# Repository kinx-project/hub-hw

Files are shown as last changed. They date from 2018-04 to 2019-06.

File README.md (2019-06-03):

This repository contains the hardware design files for the kinX USB hub, a
bus-powered 4-port (2 internal, 2 external) USB hub for use within the Kinesis
Advantage keyboard in combination with the kinX keyboard controller.

The kinX USB hub is based on the Cypress HX2VL series USB controller,
specifically the [Cypress
CY7C65632-48AXCT](http://www.cypress.com/part/cy7c65632-48axct).

The design has been created with the following resources:

* [CY7C65632-48AXCT datasheet](http://www.cypress.com/file/114101/download)
* [HX2VL: Guidelines on System Design](http://www.cypress.com/file/122726/download)
* [CY4607M (CY7C65632-48AXCT devboard) schematic and BOM](http://www.cypress.com/documentation/other-resources/reduced-bom-schematic-cy7c65642-family-hx2vl-usb-20-hub-controller)
* [Example schematic for the QFN28 version](http://www.cypress.com/file/117521/download)

You can order this PCB at [OSH Park](https://oshpark.com/shared_projects/0aJAMwpd).

You can order the components at [Digi-Key](https://www.digikey.ch/short/pm8417).

## See also

https://github.com/kinx-project/mk66f-blaster for writing the EEPROM.

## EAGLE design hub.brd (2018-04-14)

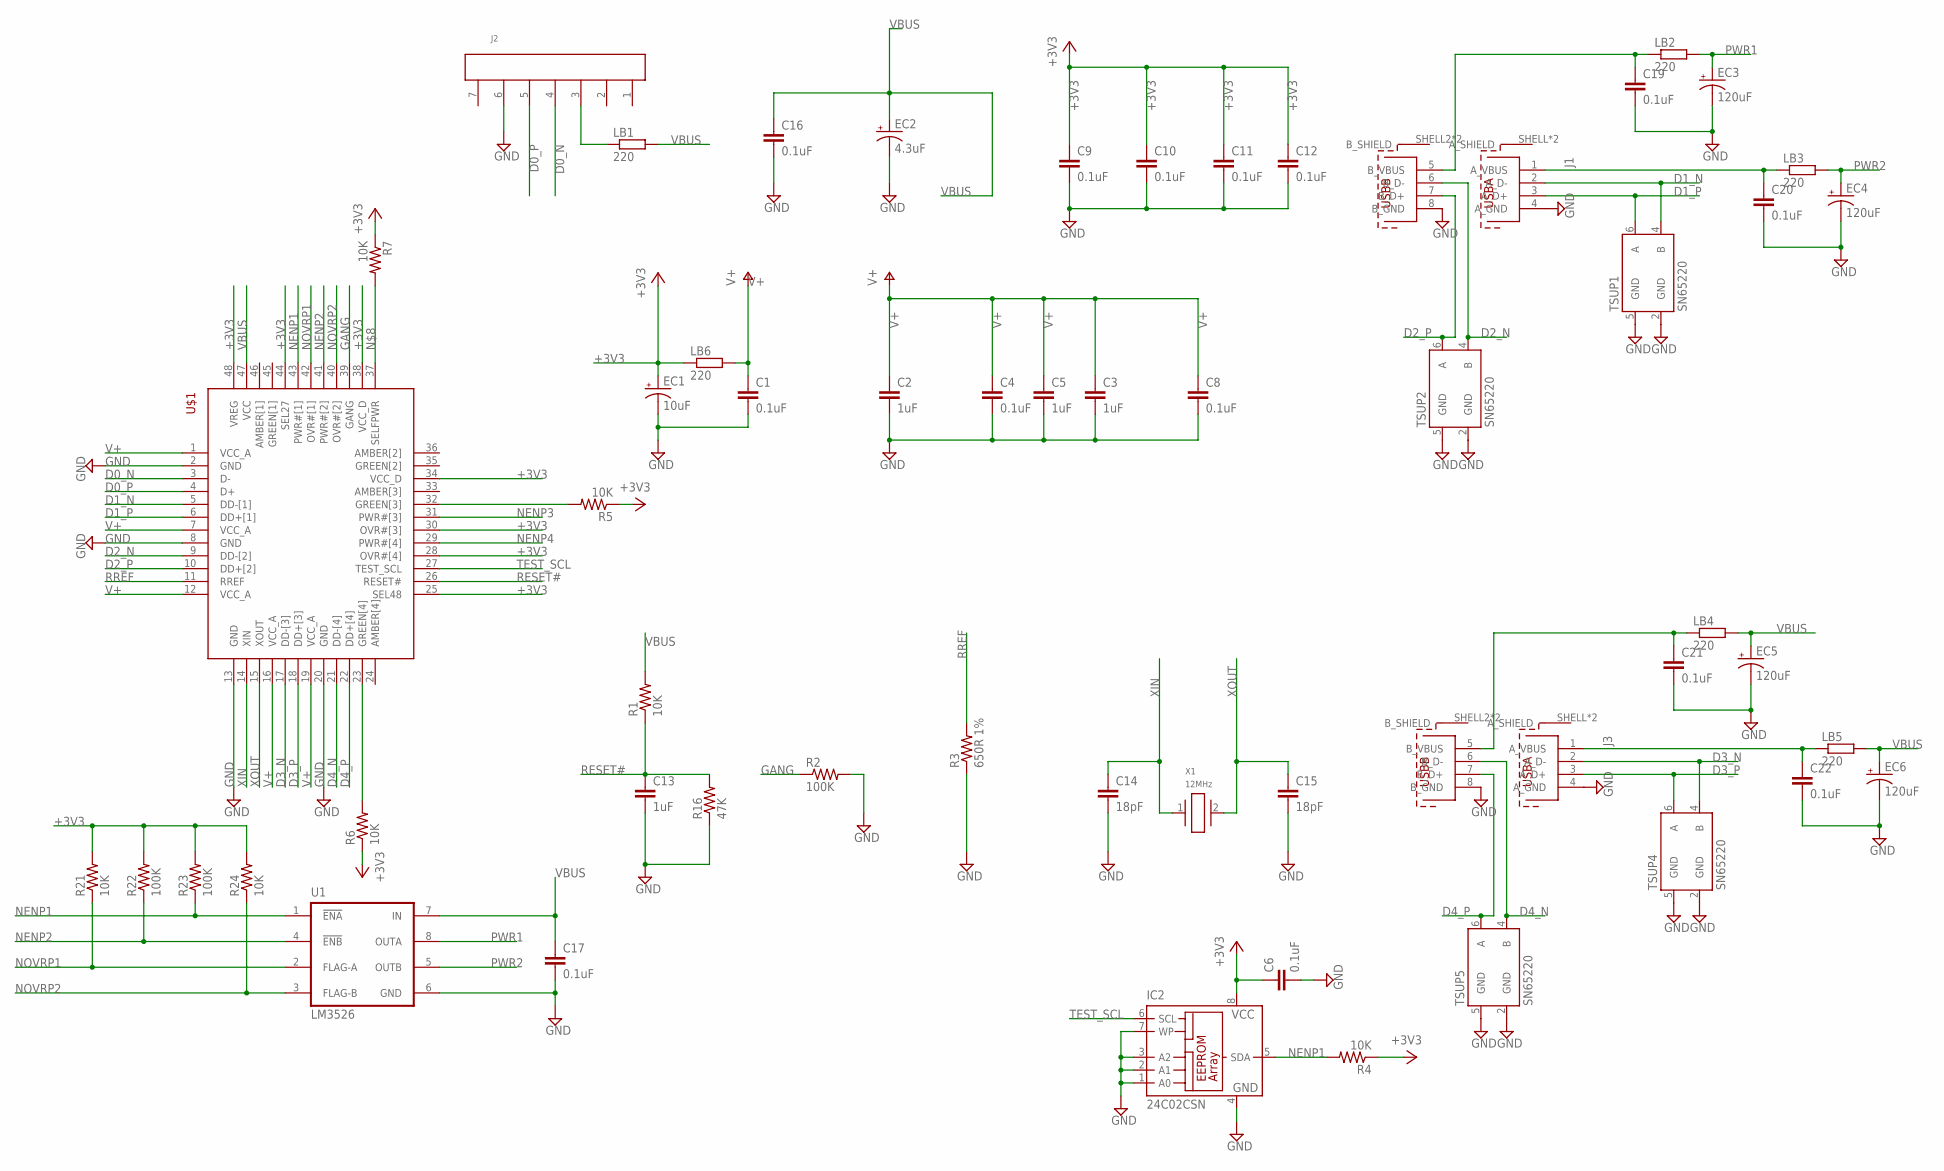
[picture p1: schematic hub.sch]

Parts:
C1, C4, C6, C8, C9, C10, C11, C12, C16, C17, C19, C20, C21, C22: 0.1uF; C0805; MPN GRM21BR71H104KA01L; DIGIKEY 732-8026-1-ND
C2, C3, C5, C13: 1uF; C0805; MPN C0805C105K4RACTU; DIGIKEY 399-1284-1-ND
C14, C15: 18pF; C0805; MPN CL21C180JBANNNC; DIGIKEY 1276-1107-1-ND
EC1: 10uF; CPOL-RADIAL-2.5MM-6.5MM; MPN UST1H100MDD1TE; DIGIKEY 493-16013-1-ND
EC2: 4.3uF; UD-5X5,8_NICHICON; MPN UUP1C4R7MCL1GS; DIGIKEY 338-3973-1-ND
EC3, EC4, EC5, EC6: 120uF; CPOL-RADIAL-2.5MM-6.5MM; MPN ELXY250ELL121MF15D; DIGIKEY 565-1791-ND
IC2: 24C02CSN; SO-08; DIGIKEY 24C02C/SN-ND
J1, J3: 61400826021; MPN 61400826021; DIGIKEY 732-2107-ND
J2: 62000711622; MPN 440054-7; DIGIKEY A100039-ND
LB1, LB2, LB3, LB4, LB5, LB6: 220; R0805; MPN BLM21PG221SN1D; DIGIKEY 490-1054-1-ND
R1, R4, R5, R6, R7, R21, R24: 10K; M0805; MPN RC0805FR-0710KL; DIGIKEY 311-10.0KCRCT-ND
R2, R22, R23: 100K; M0805; MPN RC0805FR-07100KL; DIGIKEY 311-100KCRCT-ND
R3: 650R 1%; M0805; MPN RC0805FR-07649RL; DIGIKEY 311-649CRCT-ND
R16: 47K; M0805; MPN RC0805FR-0747KL; DIGIKEY 311-47.0KCRCT-ND
TSUP1, TSUP2, TSUP4, TSUP5: SN65220; SOT23-6; MPN SN65220DBVR; DIGIKEY 296-9694-1-ND
U1: LM3526; SO08; MPN LM3526MX-L/NOPB; DIGIKEY LM3526MX-L/NOPBCT-ND
U$1: CY7C65632; TQFP48_7X7; MPN CY7C65632-48AXCT; DIGIKEY 428-3155-1-ND
X1: 12MHz; XTAL_ABLS2-24.000MHZ-D4YF-T; MPN ABLS-12.000MHZ-B2-T; DIGIKEY 535-9067-1-ND

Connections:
+3V3: C6.1, C9.1, C10.1, C11.1, C12.1, EC1.1 (+), IC2.8 (VCC), LB6.1, R4.1, R5.1, R6.1, R7.1, R21.2, R22.2, R23.2, R24.2, U$1.25 (SEL48), U$1.28 (OVR#[4]), U$1.30 (OVR#[3]), U$1.34 (VCC_D), U$1.38 (VCC_D), U$1.44 (SEL27), U$1.48 (VREG)
D0_N: J2.4, U$1.3 (D-)
D0_P: J2.5, U$1.4 (D+)
D1_N: J1.2 (A_D-), TSUP1.4 (B), U$1.5 (DD-[1])
D1_P: J1.3 (A_D+), TSUP1.6 (A), U$1.6 (DD+[1])
D2_N: J1.6 (B_D-), TSUP2.4 (B), U$1.9 (DD-[2])
D2_P: J1.7 (B_D+), TSUP2.6 (A), U$1.10 (DD+[2])
D3_N: J3.2 (A_D-), TSUP4.4 (B), U$1.17 (DD-[3])
D3_P: J3.3 (A_D+), TSUP4.6 (A), U$1.18 (DD+[3])
D4_N: J3.6 (B_D-), TSUP5.4 (B), U$1.21 (DD-[4])
D4_P: J3.7 (B_D+), TSUP5.6 (A), U$1.22 (DD+[4])
GANG: R2.1, U$1.39 (GANG)
GND: C1.2, C2.2, C3.2, C4.2, C5.2, C6.2, C8.2, C9.2, C10.2, C11.2, C12.2, C13.2, C14.2, C15.2, C16.2, C17.2, C19.2, C20.2, C21.2, C22.2, EC1.2 (-), EC2.-, EC3.2 (-), EC4.2 (-), EC5.2 (-), EC6.2 (-), IC2.1 (A0), IC2.2 (A1), IC2.3 (A2), IC2.4 (GND), IC2.7 (WP), J1.4 (A_GND), J1.8 (B_GND), J2.6, J3.4 (A_GND), J3.8 (B_GND), R2.2, R3.1, R16.1, TSUP1.2 (GND), TSUP1.5 (GND), TSUP2.2 (GND), TSUP2.5 (GND), TSUP4.2 (GND), TSUP4.5 (GND), TSUP5.2 (GND), TSUP5.5 (GND), U1.6 (GND), U$1.2 (GND), U$1.8 (GND), U$1.13 (GND), U$1.20 (GND)
unnamed: C19.1, J1.5 (B_VBUS), LB2.1
unnamed: C21.1, J3.5 (B_VBUS), LB4.1
unnamed: C22.1, J3.1 (A_VBUS), LB5.1
unnamed: C20.1, J1.1 (A_VBUS), LB3.1
unnamed: J2.3, LB1.1
unnamed: R6.2, U$1.23 (GREEN[4])
unnamed: R5.2, U$1.32 (GREEN[3])
unnamed: R7.2, U$1.37 (SELFPWR)
NENP1: IC2.5 (SDA), R4.2, R23.1, U1.1 (!ENA!), U$1.43 (PWR#[1])
NENP2: R22.1, U1.4 (!ENB!), U$1.41 (PWR#[2])
NENP3: U$1.31 (PWR#[3])
NENP4: U$1.29 (PWR#[4])
NOVRP1: R21.1, U1.2 (FLAG-A), U$1.42 (OVR#[1])
NOVRP2: R24.1, U1.3 (FLAG-B), U$1.40 (OVR#[2])
PWR1: EC3.1 (+), LB2.2, U1.8 (OUTA)
PWR2: EC4.1 (+), LB3.2, U1.5 (OUTB)
RESET#: C13.1, R1.1, R16.2, U$1.26 (RESET#)
RREF: R3.2, U$1.11 (RREF)
TEST_SCL: IC2.6 (SCL), U$1.27 (TEST_SCL)
V+: C1.1, C2.1, C3.1, C4.1, C5.1, C8.1, LB6.2, U$1.1 (VCC_A), U$1.7 (VCC_A), U$1.12 (VCC_A), U$1.16 (VCC_A), U$1.19 (VCC_A)
VBUS: C16.1, C17.1, EC2.+, EC5.1 (+), EC6.1 (+), LB1.2, LB4.2, LB5.2, R1.2, U1.7 (IN), U$1.47 (VCC)
XIN: C14.1, U$1.14 (XIN), X1.1
XOUT: C15.1, U$1.15 (XOUT), X1.2

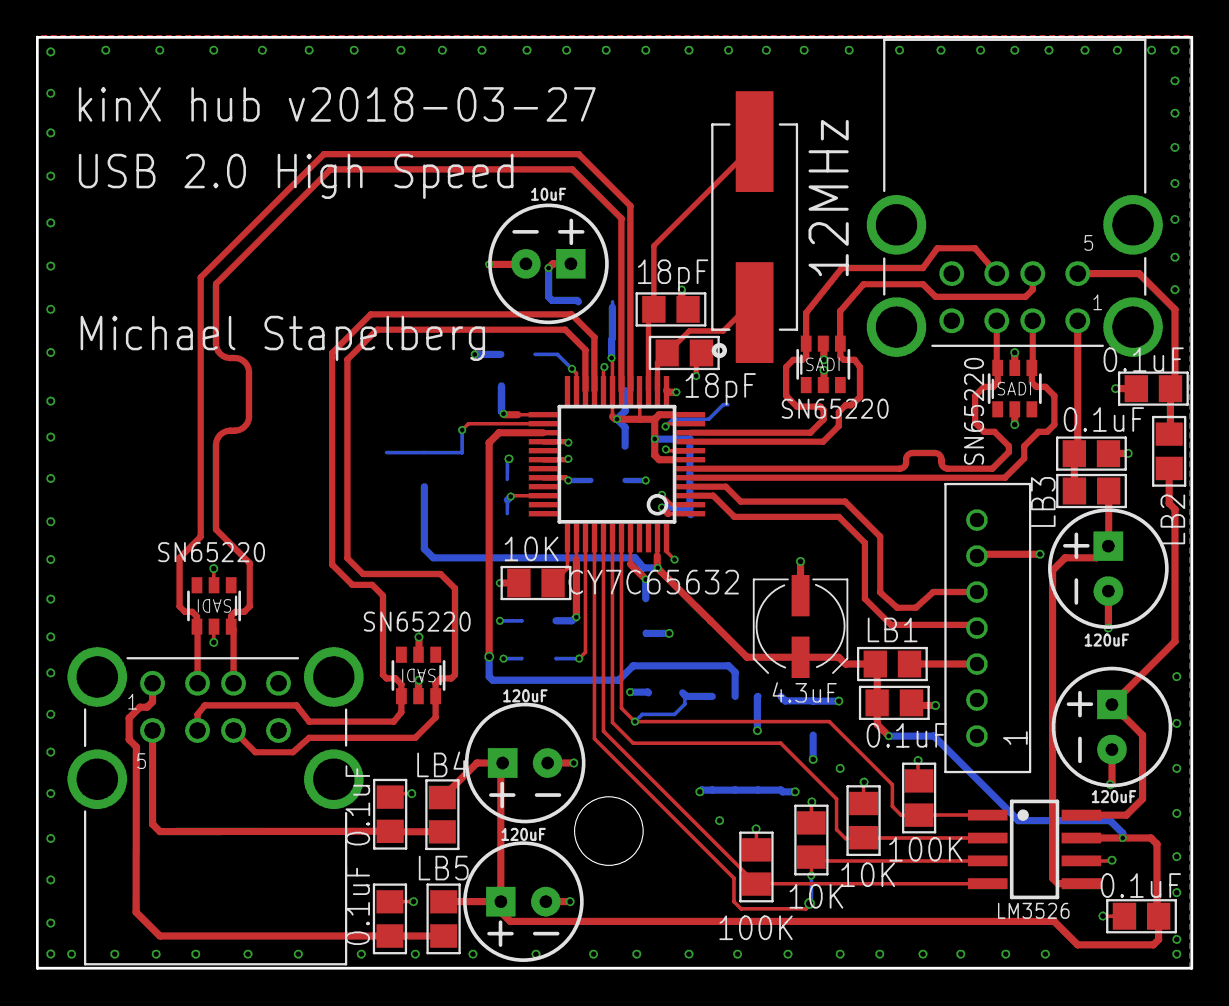
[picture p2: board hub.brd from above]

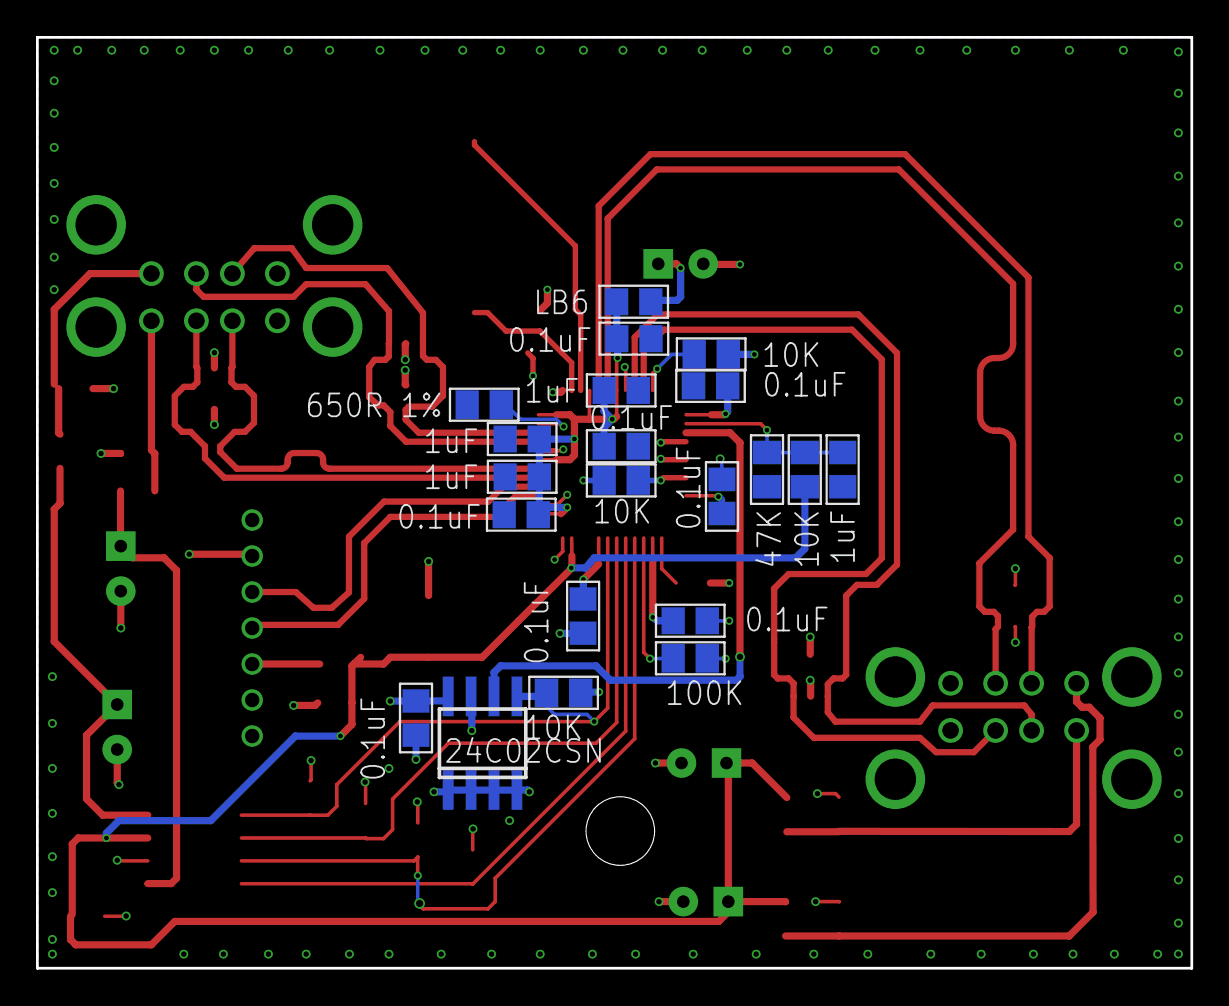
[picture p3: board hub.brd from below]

Board: 4 copper layers, 64.1 x 51.7 mm, 55 parts (21 on the bottom side), 34 nets.

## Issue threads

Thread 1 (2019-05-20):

eagle version="8.4.3"

jm4r7in, 2019-05-20:
Hello,
Could you save the EAGLE files for older versions (like 7.4) ?
Thank you!

stapelberg, 2019-05-20:
I’m not sure how I would do that.

I don’t even have a valid subscription of eagle at the moment.

My medium- to longer-term plan is to convert the project to KiCad going forward.

Sorry that I’m not able to help with this.

jm4r7in, 2019-05-21:
Thank you for your quick answer !
There is an option in Eagle 8 to save the files in Eagle 7 format. You can find this option in File>save as Eagle 7.x
Do you have at least a screenshot or pdf of your schematics ?
Thank you.

stapelberg, 2019-05-21:
I attached a PDF of the schematic after importing the project into KiCad. I suggest you just import the project in KiCad yourself, it only takes a second (File → Import → Eagle CAD).

[hub-schematic.pdf](https://github.com/kinx-project/hub-hw/files/3202617/hub-schematic.pdf)

jm4r7in, 2019-05-24:
Thank you.

janncker, 2019-05-26:
[hub_hw_v7.x.zip](https://github.com/kinx-project/hub-hw/files/3220235/hub_hw_v7.x.zip)

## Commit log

2018-03-27 Add USB 2.0 High Speed hub schematic/board
    …as of 34c3.
    [hub.brd, hub.sch]
2018-03-27 switch to crystal with correct drive level (supporting 600μW)
    [hub.brd, hub.sch]
2018-03-27 pick 18pF caps
    [hub.brd, hub.sch]
2018-03-27 Switch to 0805 capacitors for consistency
    [hub.brd, hub.sch]
2018-03-27 Switch EC3, EC4, EC5, EC6 to ELXY250ELL121MF15D from vendor BOM
    [hub.brd, hub.sch]
2018-03-27 update EC1 with same footprint as EC3-EC6
    [hub.brd, hub.sch]
2018-03-27 pick ferrite beads
    [hub.brd, hub.sch]
2018-03-27 pick wire-to-board connector
    [hub.brd, hub.sch]
2018-03-27 pick USB transient suppressors
    [hub.brd, hub.sch]
2018-03-27 pick resistors
    [hub.brd, hub.sch]
2018-03-27 pick capacitors
    [hub.brd, hub.sch]
2018-03-27 add and connect I2C EEPROM
    [hub.brd, hub.sch]
2018-03-27 complete BOM
    [hub.brd, hub.sch]
2018-03-27 enlarge drill holes for DRC
    [hub.brd]
2018-03-27 finish pin-strapping
    [hub.brd, hub.sch]
2018-03-27 move vias for DRC
    [hub.brd]
2018-03-27 re-route USB for oshpark PCBs
    [hub.brd, hub.sch]
2018-03-27 silkscreen: better direction marking for SN65220
    [hub.brd, hub.sch]
2018-03-27 finish silk screen
    [hub.brd, hub.sch]
2018-03-27 silkscreen improvements
    [hub.brd, hub.sch]
2018-03-27 add part outline to tPlace layer for R, C, L parts
    For a nicer silkscreen :)
    [hub.brd, hub.sch]
2018-03-27 BOM fix: swap 0603 18pF caps for 0805
    [hub.brd, hub.sch]
2018-03-27 give crystal more space
    [hub.brd]
2018-03-27 BOM fix: swap 0603 649R for 0805
    [hub.brd, hub.sch]
2018-03-27 fix EC1 silkscreen
    [hub.brd]
2018-03-27 pin-strap SELFPWR to +3V3 (bus-powered → self-powered)
    [hub.brd, hub.sch]
2018-03-27 add BOM to git
    [hub.digikey.csv]
2018-03-27 update silkscreen for new revision
    [hub.brd]
2018-04-14 Change 0.1μF capacitors from 490-1666-1-ND to 732-8026-1-ND
    The former is no longer available.
    [hub.brd, hub.digikey.csv, hub.sch]
2018-04-14 Rename bom to bom.digikey.csv for consistency with mk66f-hw
    [bom.digikey.csv]
2018-04-14 add USB cables to BOM
    [bom.digikey.csv]
2019-06-03 update digikey BOM

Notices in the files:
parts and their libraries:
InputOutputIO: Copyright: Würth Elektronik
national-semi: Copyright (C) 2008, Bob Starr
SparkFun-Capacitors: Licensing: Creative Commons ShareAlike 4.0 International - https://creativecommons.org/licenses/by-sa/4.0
